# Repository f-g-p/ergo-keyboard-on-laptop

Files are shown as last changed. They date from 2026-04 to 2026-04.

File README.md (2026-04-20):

# ergo-keyboard-on-laptop

Printable plates that hold a split ergonomic keyboard on top of a laptop, so you never have to fall back to the built-in keyboard.

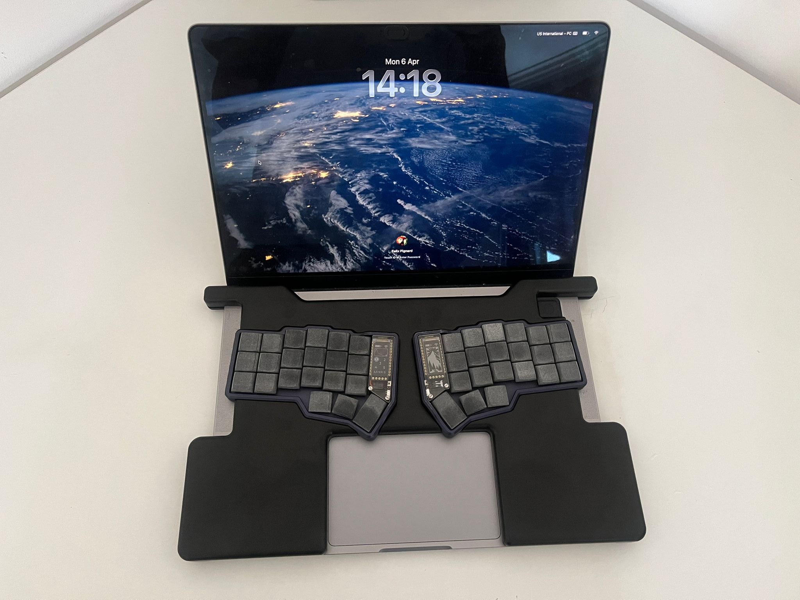
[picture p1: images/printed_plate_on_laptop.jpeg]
The printed plate, mounted on a laptop


## Why

This setup is especially useful when:

- working in transit (train, plane)
- attending onsite meetings
- browsing from the sofa, a hammock, or anywhere else away from a desk

## Finding the right plate

Plates are organised by laptop model and then by keyboard model, under `files/<laptop>/<keyboard>/`. Available plates today:

```
files/
├── any_laptop/
│   └── any_keyboard/
└── macbook_pro_14/
    ├── any_keyboard/
    └── typeractive_corne/
```

Browse the hierarchy, pick the folder that matches your hardware, and read the local `README.md` for details and caveats specific to that plate.

## Printing

Each folder contains the plate in several formats:

- `plate.step` — recommended format for CNC machining services.
- `plate.stl` — for 3D printing (not recommended, see below).
- `plate.f3d` — Fusion 360 source file. Open this to edit or remix the design.

Upload any of them to an online manufacturing service and follow their ordering form.

**Recommendation: CNC-machined aluminium, not 3D printing.** The plate has wide 2 mm-thick sections that would be fragile when printed in plastic.

Personally, I used [jlccnc.com](https://jlccnc.com) for mine; expect a cost of around €150 per plate.

**Tip:** you can visualise any plate online by clicking its `.step` file on GitHub.

## Gallery

Renders of each plate available in this repository:

| Plate | Render |
| --- | --- |
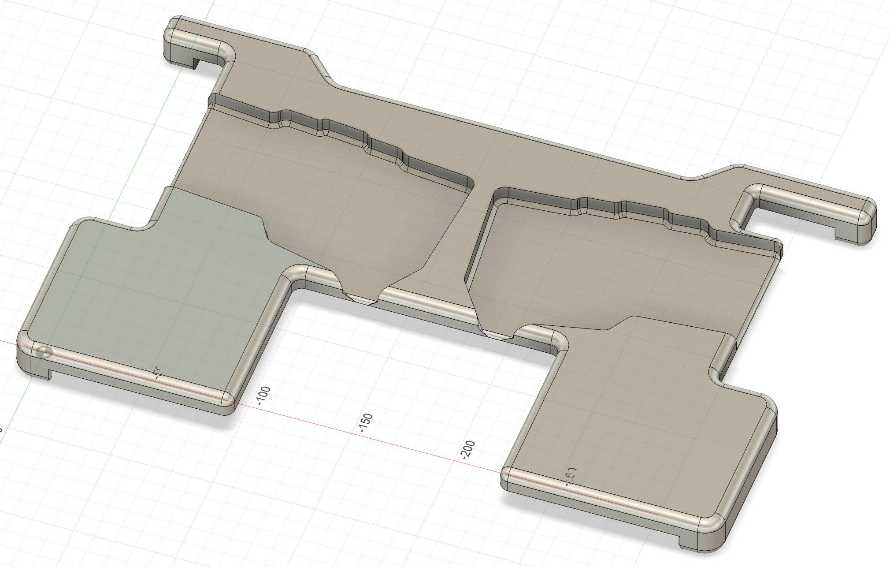
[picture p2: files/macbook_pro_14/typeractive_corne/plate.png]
Render of the MacBook Pro 14" plate tailored for the Typeractive Corne
| [MacBook Pro 14" — Typeractive Corne](files/macbook_pro_14/typeractive_corne/) |  |
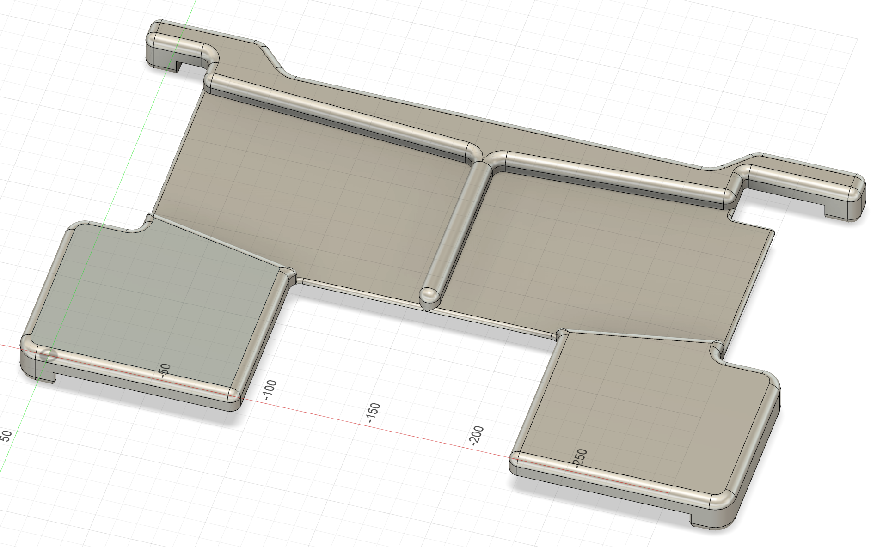
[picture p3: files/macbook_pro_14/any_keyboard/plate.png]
Render of the MacBook Pro 14" plate for any keyboard
| [MacBook Pro 14" — Any split keyboard](files/macbook_pro_14/any_keyboard/) |  |
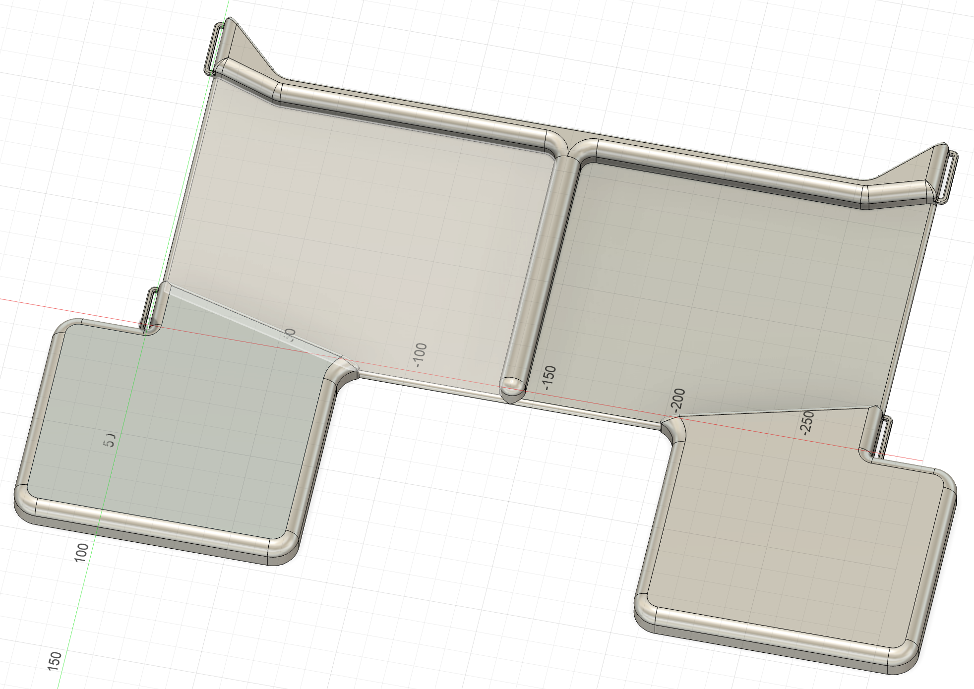
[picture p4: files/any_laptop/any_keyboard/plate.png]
Render of the generic plate
| [Any laptop — Any split keyboard](files/any_laptop/any_keyboard/) |  |

## Contributing

Please open an issue to suggest refinements or additional plate models to support. Let's discuss before jumping in long 3D designing

## Support the project

If you printed a plate and enjoy it, you can say thank you by buying me a coffee :)



## License

Released under the [Creative Commons Attribution 4.0 International](LICENSE) license. You are free to print, share, remix, and use the plates — including commercially — provided you credit the project.

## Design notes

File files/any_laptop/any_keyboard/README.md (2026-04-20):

# Any laptop — Any split keyboard

A generic plate designed to work with most laptops and most split ergonomic keyboards.



## Laptop compatibility

This plate does **not** clip onto the laptop. It is meant to be strapped on, using the mounting holes on each side.

A recommended fixation system: [adjustable reusable fastening straps on Amazon](https://www.amazon.fr/WSZJINB-Adjustable-Reusable-Fastening-Management/dp/B09YPZBSMK).

## Keyboard compatibility

The extruded section is intentionally oversized so that a wide range of split keyboards fit on top. You can simply place your keyboard on the plate and start typing.

**Tip:** before placing an order, print the `.stl` at 1:1 scale on paper and check that the outline matches your laptop and keyboard. It's the cheapest way to catch a sizing mistake.

Once you have found your preferred keyboard position and want to lock it in, you can adapt the plate in either of the following ways:

- **Drill holes** in the plate matching the location of the keyboard's rubber feet.
- **Add bumps** (for example, glued-on stops) inside the extruded section, around the keyboard's footprint, to prevent it from sliding.

## Specifications

- **Outer dimensions:** 350 × 235 mm
- **Thickness:** 11 mm
- **Recommended material:** Aluminium, CNC-machined
- **Approximate weight:** 450 g

## What's in this folder

- `plate.step` — recommended format for CNC machining services.
- `plate.stl` — for 3D printing (less recommended, see the [main README](../../../README.md)).
- `plate.f3d` — Fusion 360 source file. Open this to edit or remix the design.

## Caveats

- The laptop's built-in keyboard is covered while the plate is mounted. The trackpad is still accessible.
- The plate must be removed before closing the laptop lid.
- Check that your laptop's cooling vents are not obstructed by the plate.
- The straps add a small amount of thickness under the laptop base. This should be in line with the laptop rubber feet.

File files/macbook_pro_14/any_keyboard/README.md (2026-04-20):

# MacBook Pro 14" — Any split keyboard

A plate shaped for the Apple MacBook Pro 14", compatible with most split ergonomic keyboards.



## Laptop compatibility

This plate is designed specifically for the **Apple MacBook Pro 14"**. It will not fit other laptop models.

Because the shape is tailored to that chassis, it offers several advantages:

- **No straps needed.** The plate clips around the laptop; ports remain accessible.
- **Screen protection.** When the lid closes, the frame rests on the plate before it reaches the screen.
- **Touch ID stays usable.** The Touch ID key is left uncovered.
- **Clean look.** The outline follows the lines of the MacBook chassis.

## Keyboard compatibility

The extruded section is intentionally oversized so that a wide range of split keyboards fit on top. You can simply place your keyboard on the plate and start typing.

**Tip:** before placing an order, print the `.stl` at 1:1 scale on paper and check that the outline matches your laptop and keyboard. It's the cheapest way to catch a sizing mistake.

Once you have found your preferred keyboard position and want to lock it in, you can adapt the plate in either of the following ways:

- **Drill holes** in the plate matching the location of the keyboard's rubber feet.
- **Add bumps** (for example, glued-on stops) inside the extruded section, around the keyboard's footprint, to prevent it from sliding.

## Specifications

- **Outer dimensions:** 345 × 220 mm
- **Thickness:** 22 mm
- **Recommended material:** Aluminium, CNC-machined
- **Approximate weight:** 600 g

## What's in this folder

- `plate.step` — recommended format for CNC machining services.
- `plate.stl` — for 3D printing (less recommended, see the [main README](../../../README.md)).
- `plate.f3d` — Fusion 360 source file. Open this to edit or remix the design.

## Notes

- The MacBook's built-in keyboard is covered except for the Touch ID key. The trackpad is still accessible.
- The lid can't be closed with the plate in place; But the plate acts as a spacer and protects the screen. The lid frame will touche the plate before the screen can.
- The MacBook Pro 14" speakers and side vents remain clear.

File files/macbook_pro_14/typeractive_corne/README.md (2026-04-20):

# MacBook Pro 14" — Typeractive Corne

A plate shaped for the Apple MacBook Pro 14" and tailored to the Typeractive Corne keyboard.



## Laptop compatibility

This plate is designed specifically for the **Apple MacBook Pro 14"**. It will not fit other laptop models.

Because the shape is tailored to that chassis, it offers several advantages:

- **No straps needed.** The plate clips around the laptop; ports remain accessible.
- **Screen protection.** When the lid closes, the frame rests on the plate before it reaches the screen.
- **Touch ID stays usable.** The Touch ID key is left uncovered.
- **Clean look.** The outline follows the lines of the MacBook chassis.

## Keyboard compatibility

This plate is made for the **Typeractive Corne, 6 columns, aluminium frame**. The extruded section matches the keyboard's outline exactly, so:

- the keyboard is held in place without any further adaptation;
- the overall look is sleeker than with the generic plate.

If you own a different keyboard, use the generic [`macbook_pro_14/any_keyboard`](../any_keyboard/) plate instead.

## Specifications

- **Outer dimensions:** 345 × 220 mm
- **Thickness:** 22 mm
- **Recommended material:** Aluminium, CNC-machined
- **Approximate weight:** 550 g

## What's in this folder

- `plate.step` — recommended format for CNC machining services.
- `plate.stl` — for 3D printing (less recommended, see the [main README](../../../README.md)).
- `plate.f3d` — Fusion 360 source file. Open this to edit or remix the design.

## Notes

- The MacBook's built-in keyboard is covered except for the Touch ID key. The trackpad is still accessible.
- The lid can't be closed with the plate in place; But the plate acts as a spacer and protects the screen. The lid frame will touche the plate before the screen can.
- The MacBook Pro 14" speakers and side vents remain clear.

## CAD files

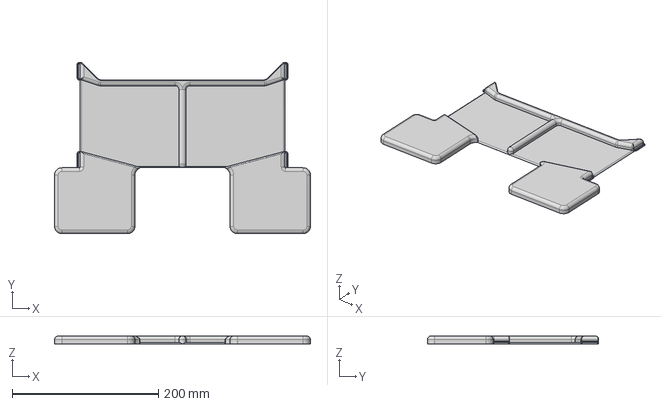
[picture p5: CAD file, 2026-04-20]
files/any_laptop/any_keyboard/plate.step
350.0 x 234.0 x 11.0 mm

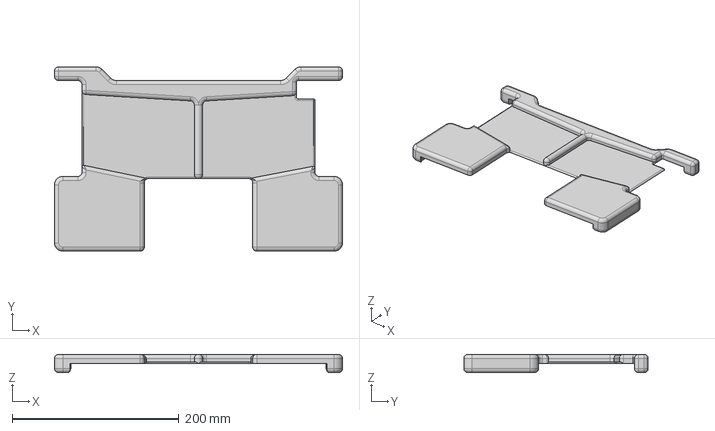
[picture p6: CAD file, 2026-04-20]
files/macbook_pro_14/any_keyboard/plate.step
345.6 x 221.2 x 22.0 mm

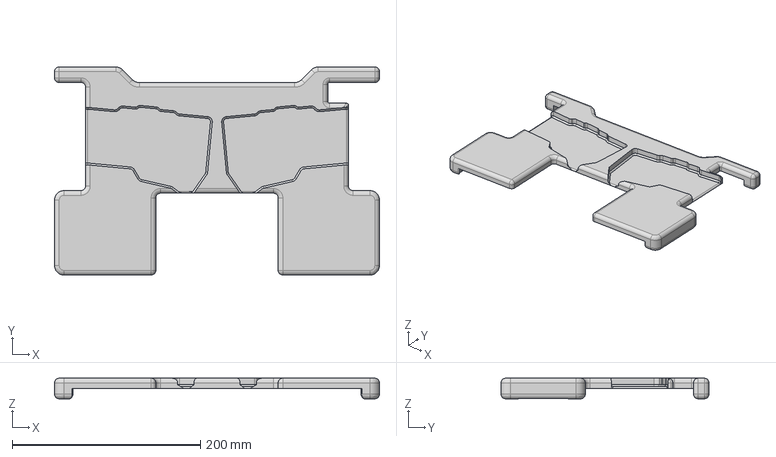
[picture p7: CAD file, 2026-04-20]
files/macbook_pro_14/typeractive_corne/plate.step
345.6 x 221.2 x 22.0 mm

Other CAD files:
files/any_laptop/any_keyboard/plate.f3d
files/any_laptop/any_keyboard/plate.stl
files/macbook_pro_14/any_keyboard/plate.f3d
files/macbook_pro_14/any_keyboard/plate.stl
files/macbook_pro_14/typeractive_corne/plate.f3d
files/macbook_pro_14/typeractive_corne/plate.stl
